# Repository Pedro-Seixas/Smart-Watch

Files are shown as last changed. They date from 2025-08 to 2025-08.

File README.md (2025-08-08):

# Smart-Watch
A custom low-power stm32-based wearable smart watch

## Features
- 6-Axis IMU Sensor for motion detection and pedometer.
- Temperature Sensor
- OLED Display
- Powered by 3.7V battery or USB
- 2 programmable switches
- Real-Time Clock
- Tap Sensor

## Pinout Diagram


## Schematic
schematic_page-0001

## PCB
<p align="center">
watch-front
watch-back
</p>

## Demo (Clock | Menu | Sensors)
<p align="center">



</p>

If you would like to clone the repo, see the "How to" in the Docs folder.

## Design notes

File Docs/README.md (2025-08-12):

# How to get it working

## Softwares needed:
- STM32CubeIDE
- STM32CubeProgrammer

## Install necessary files
- Clone the repository to a folder and in STM32CubeIDE open the project

## Upload to the device
- Build the project and open STM32CubeProgrammer.
- Select USB since we are doing DFU (See 1).
- Click "Open File" and navigate to your project folder, go to the Debug folder and select the file with the .elf extension (See 2).
- Remove the device from the USB, hold the boot button (SW2) and connect the device to the computer. Release the boot button.
- Click the refresh icon in the STM32CubeProgrammer software (See 3), it should find the device. Now, click in "Connect" (See 4). Finally, click in "Download" (See 5).
- After the download is complete, press the Reset button (SW1) or remove and connect the USB.



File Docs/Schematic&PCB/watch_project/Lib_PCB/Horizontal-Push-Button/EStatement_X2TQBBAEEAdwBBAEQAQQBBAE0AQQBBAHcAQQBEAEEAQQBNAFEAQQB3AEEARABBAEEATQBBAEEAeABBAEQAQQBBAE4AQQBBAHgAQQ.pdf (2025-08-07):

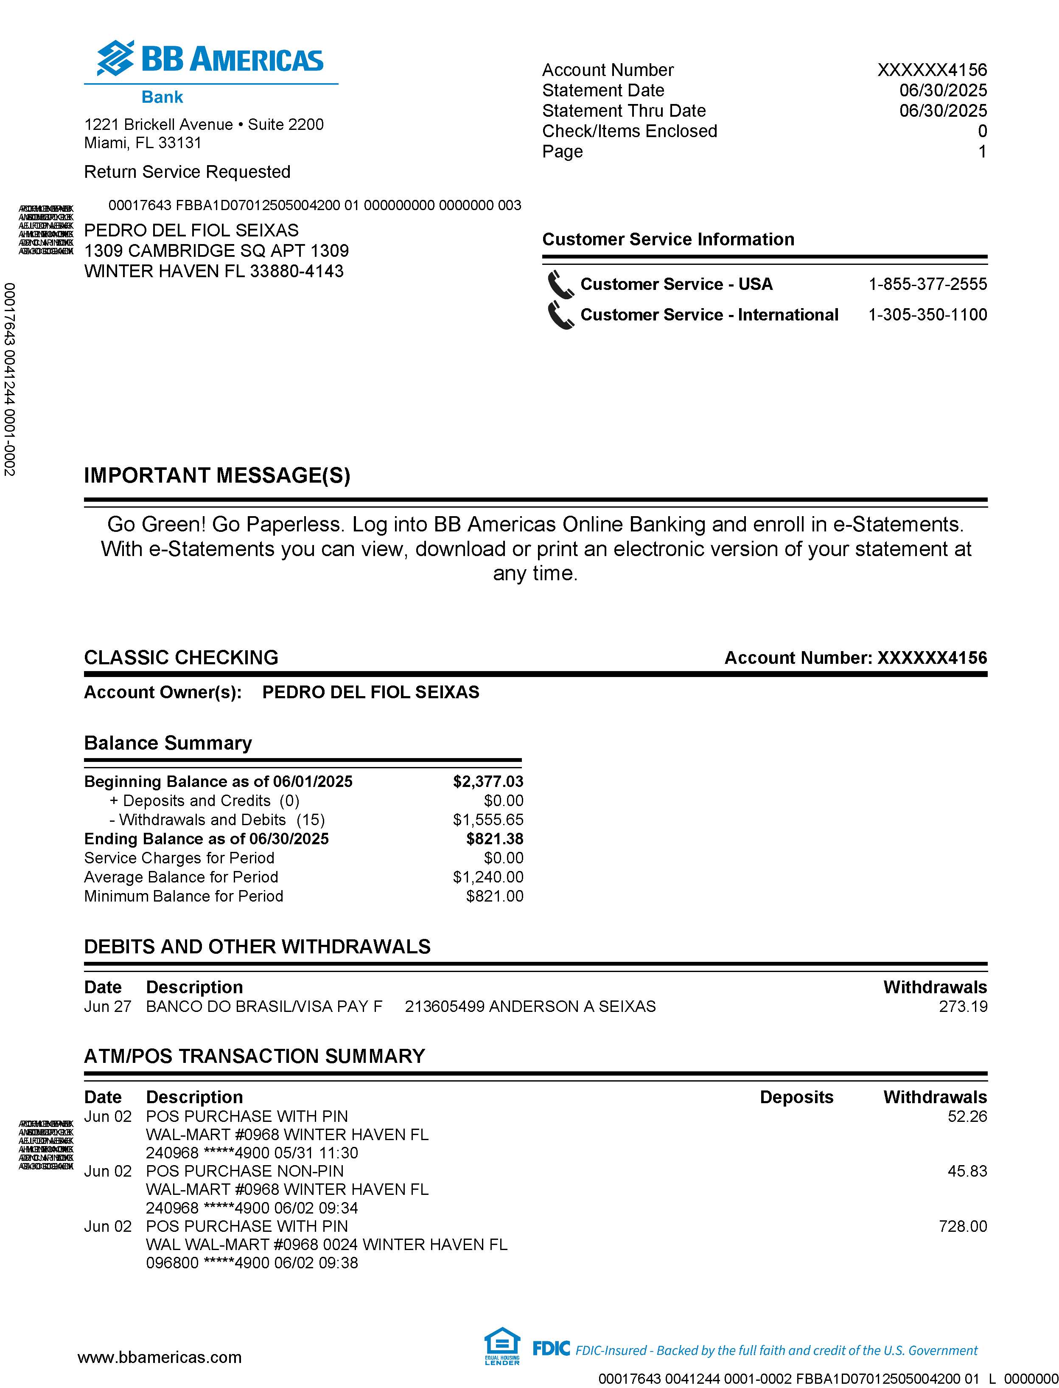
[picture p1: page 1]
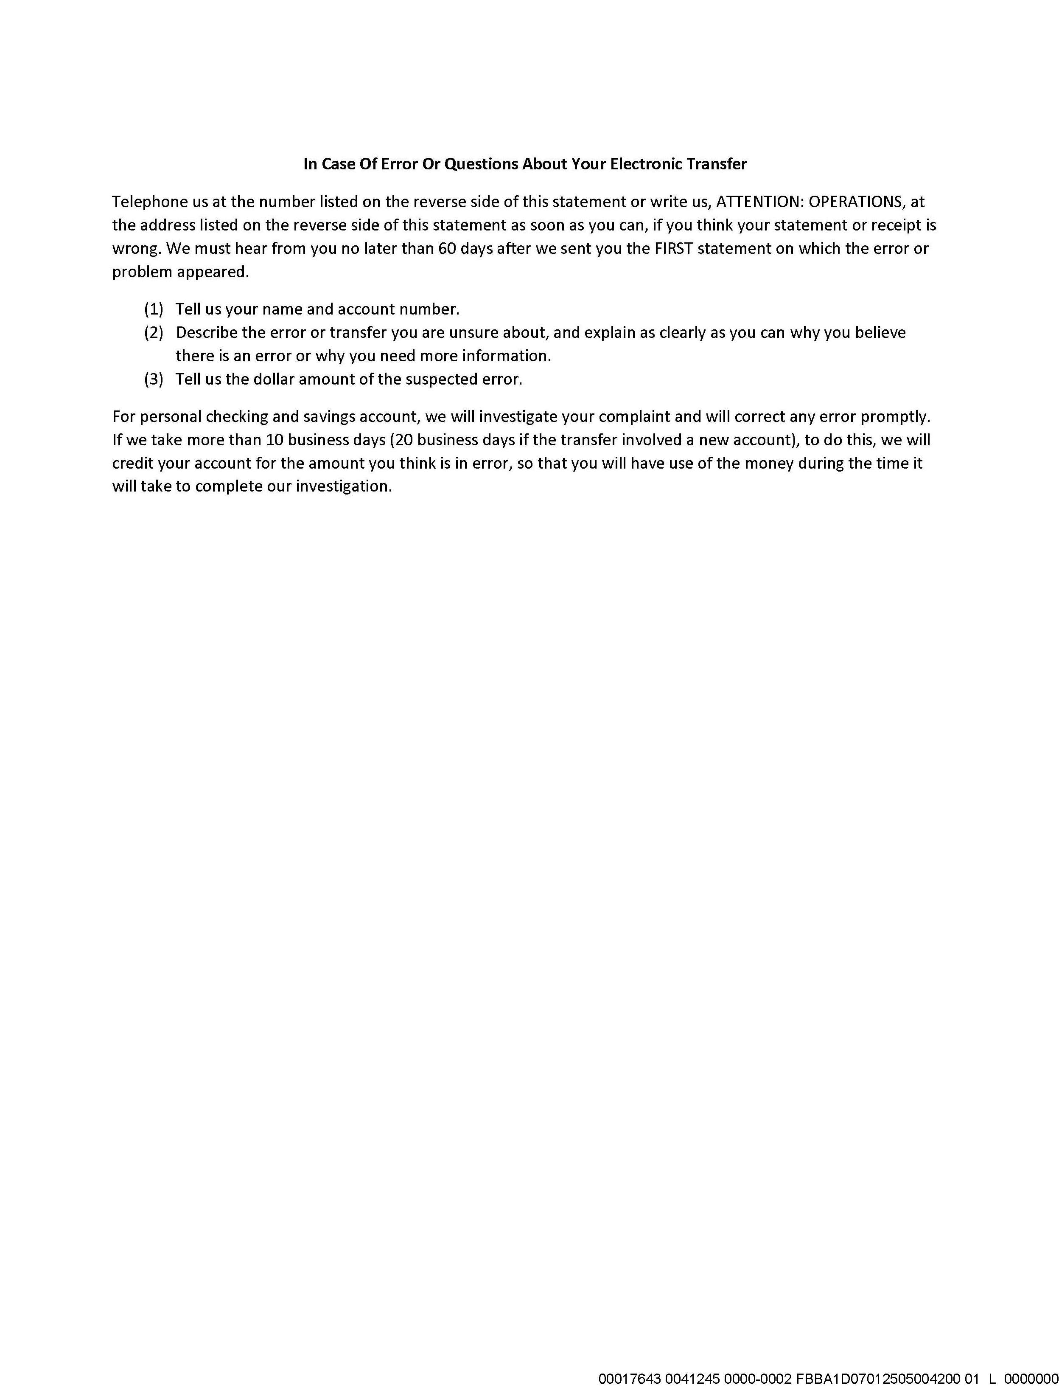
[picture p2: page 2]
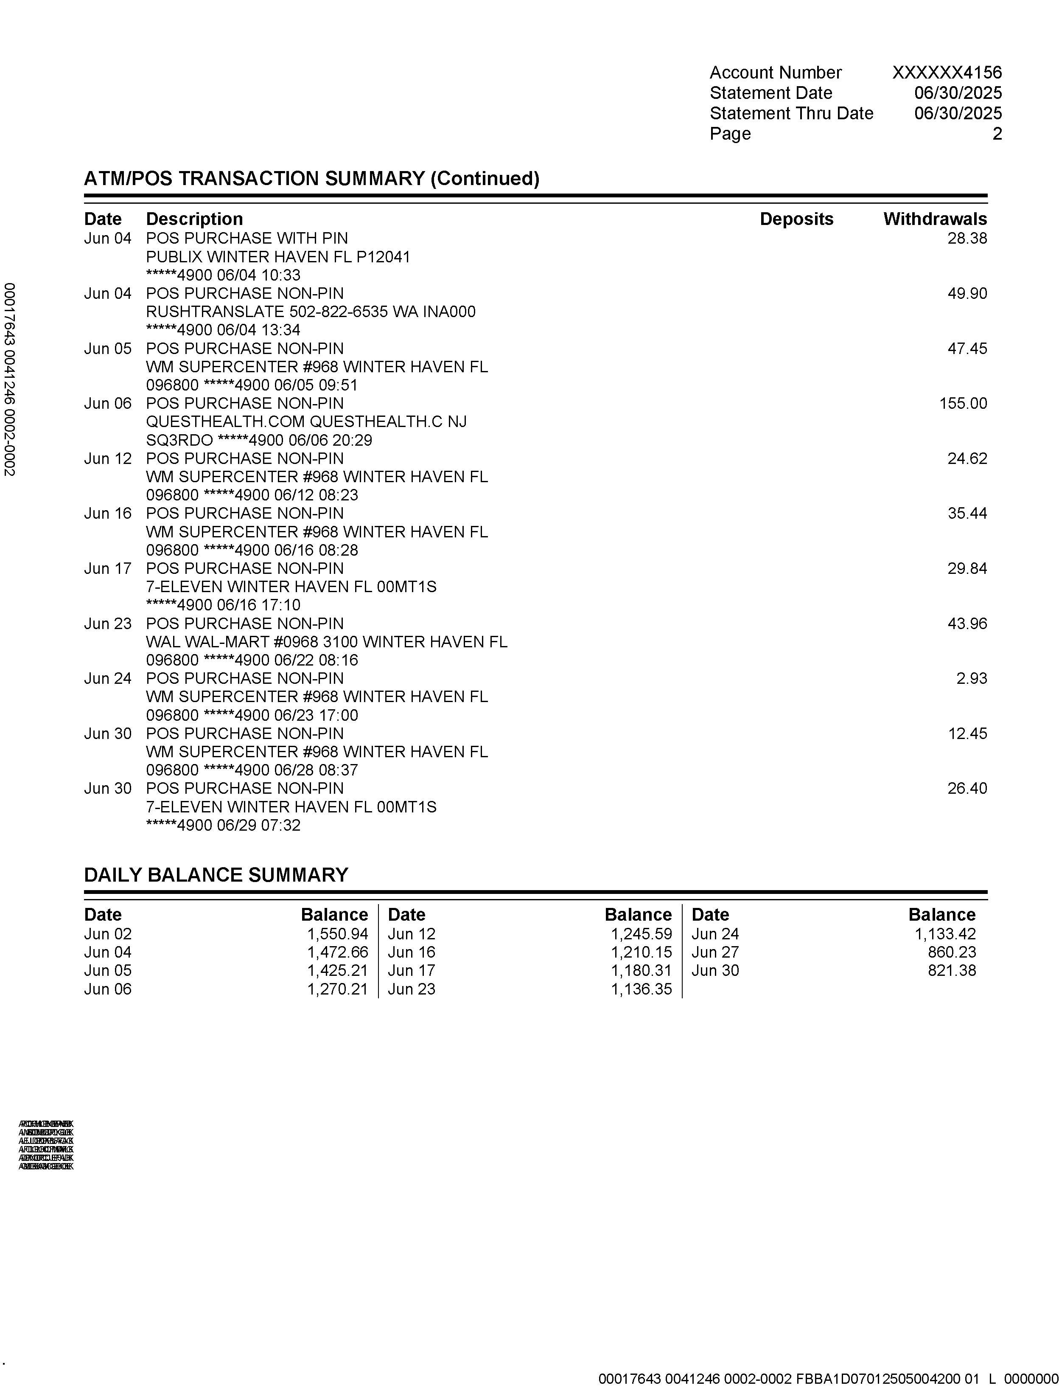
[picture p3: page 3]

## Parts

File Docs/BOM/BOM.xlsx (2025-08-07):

Comment | Designator | Footprint | Part Number
STM32 Microprocessor | U2 | Package_QFP:LQFP-48_7x7mm_P0.5mm | C465977
32.768 kHz Clock | X1 | Watch-PCB-Lib:FC-135R_L3.2-W1.5 | C32346
8 MHz Clock | X3 | Watch-PCB-Lib:CRYSTAL-SMD_4P-L3.2-W2.5-BL | C400090
0603 100nF Capacitor | C1, C2, C3, C5, C7, C8, C11, C12, C21 | Capacitor_SMD:C_0603_1608Metric | C49678
0603 10uF Capacitor | C4 | Capacitor_SMD:C_0603_1608Metric | C19702
0805 1uF Capacitor | C6, C13, C14, C17, C18, C23 | Capacitor_SMD:C_0805_2012Metric | C28323
0805 2uF Capacitor | C22 | Capacitor_SMD:C_0805_2012Metric | C5448893
0402 10pF Capacitor | C9, C10 | Capacitor_SMD:C_0402_1005Metric | C466222
0402 15pF Capacitor | C15, C16 | Capacitor_SMD:C_0402_1005Metric | C18220924
Schottky Diode | D1, D2 | Watch-PCB-Lib:SOD-123_L2.7-W1.6-LS3.7-RD | C82544
LED | D3 | Watch-PCB-Lib:LED0805-R-RD | C84256
2-P Header | J1 | Watch-PCB-Lib:HDR-TH_2P-P2.00-H-M_2005WR-2P | C6837611
MicroUSB Connector | J3 | Watch-PCB-Lib:MICRO-USB-SMD_5P-P0.65-H-F_C10418 | C10418
OLED Display | OLED1 | Watch-PCB-Lib:OLED_0.96-30P-P0.70-12864 | C2890596
0805 10kohms Resistor | R1, R2, R3, R5, R6, R7 | Resistor_SMD:R_0805_2012Metric | C17414
0603 1.5kohms Resistor | R4 | Resistor_SMD:R_0603_1608Metric | C22843
0805 270ohms Resistor | R8 | Resistor_SMD:R_0805_2012Metric | C17590
0805 390kohms Resistor | R9 | Resistor_SMD:R_0805_2012Metric | C17656
SMD Push Button | SW1, SW2 | Watch-PCB-Lib:SW-SMD_L3.9-W3.0-P4.45 | C720477
Horizontal Push Button | SW3, SW4 | Watch-PCB-Lib:KEY-TH_K2-1109DE-CXXW-XX | C455252
Accelerometer and Gyroscope | U1 | Watch-PCB-Lib:LGA-14_L3.0-W2.5-P0.50-TL | C967633
LDO 3.3V | U3 | Package_TO_SOT_SMD:SOT-23-5 | C51118

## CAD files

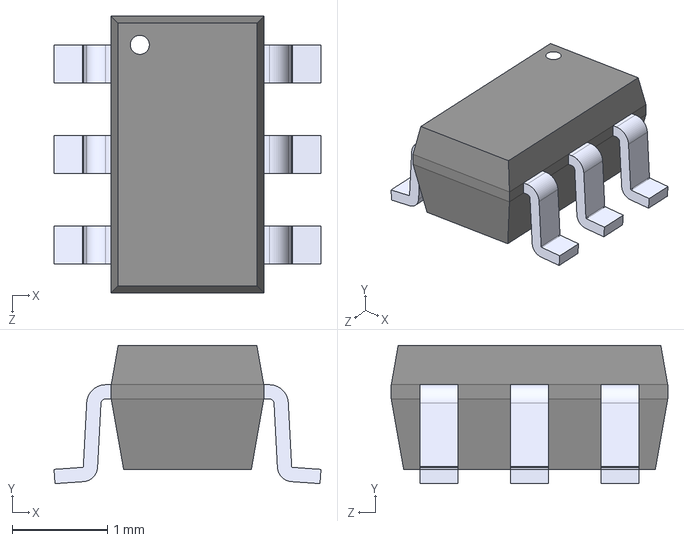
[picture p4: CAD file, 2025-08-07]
Docs/Schematic&PCB/watch_project/Lib_PCB/DW01A/DW01A.step
2.80 x 1.45 x 2.90 mm

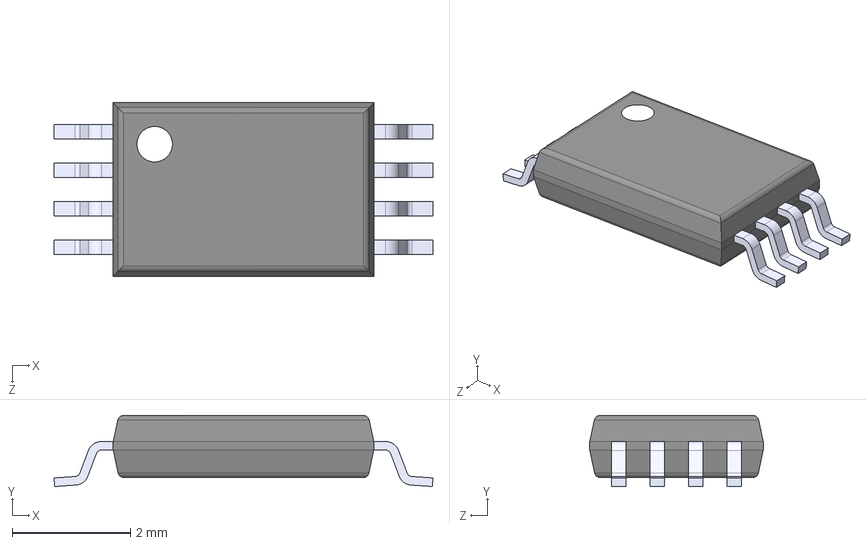
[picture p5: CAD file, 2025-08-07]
Docs/Schematic&PCB/watch_project/Lib_PCB/MOSFETSS/FS8205A.step
6.40 x 1.20 x 2.93 mm

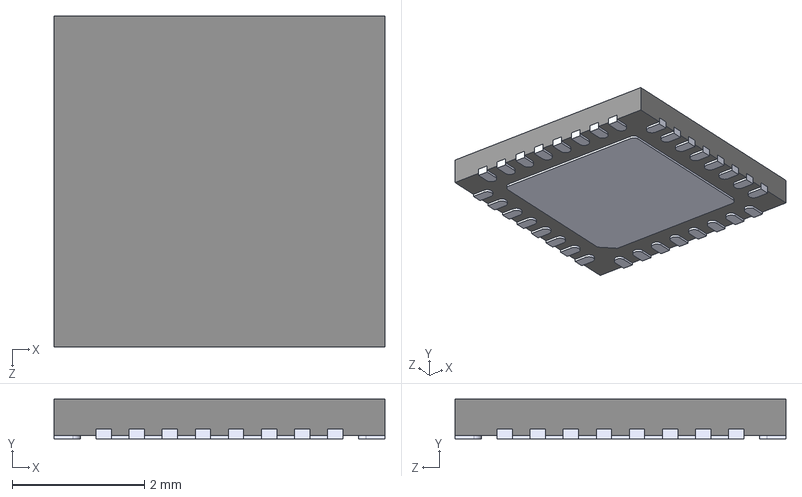
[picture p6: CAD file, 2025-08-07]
Docs/Schematic&PCB/watch_project/Lib_PCB/STM/QFN50P500X500X60-33N.step
5.00 x 0.6 x 5.00 mm

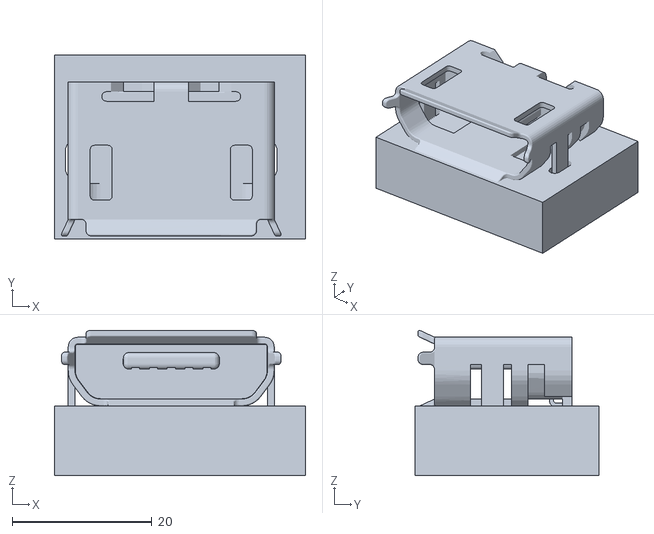
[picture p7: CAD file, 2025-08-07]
Docs/Schematic&PCB/watch_project/Lib_PCB/USB-Connector/OBJ_MICRO-USB-SMD_5P-P0.65-H-F_C10418.obj
36.0 x 26.3 x 20.8

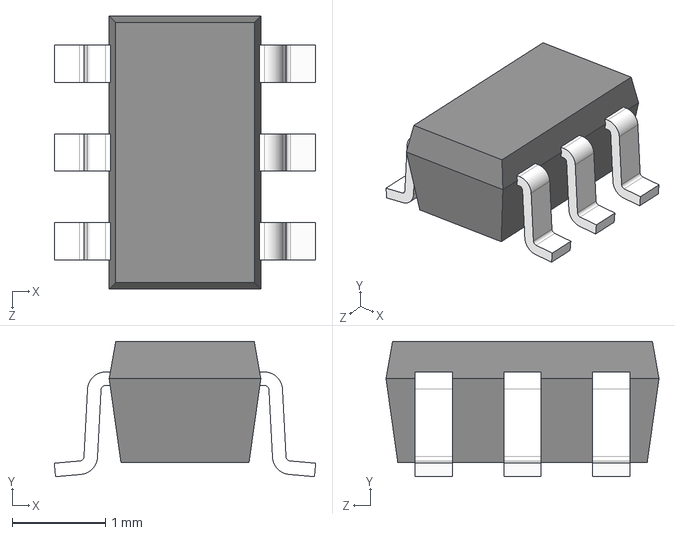
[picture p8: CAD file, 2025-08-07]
Docs/Schematic&PCB/watch_project/Lib_PCB/USBLC6-2SC6/USBLC6-2SC6.step
2.80 x 1.45 x 2.92 mm

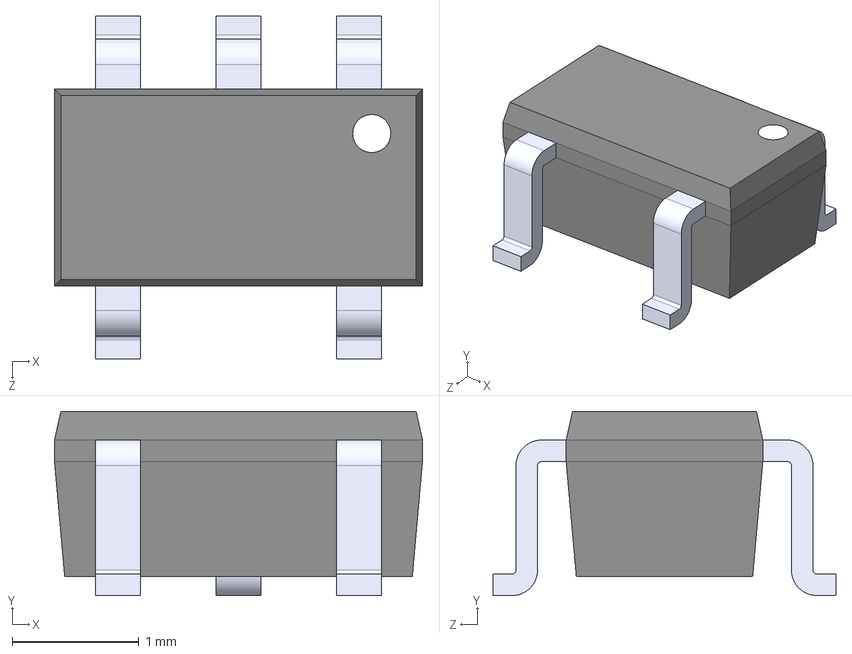
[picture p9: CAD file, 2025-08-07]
Docs/Schematic&PCB/watch_project/Lib_PCB/ICCharger/MCP73831T-4ADI_OT.step
2.90 x 1.45 x 2.70 mm

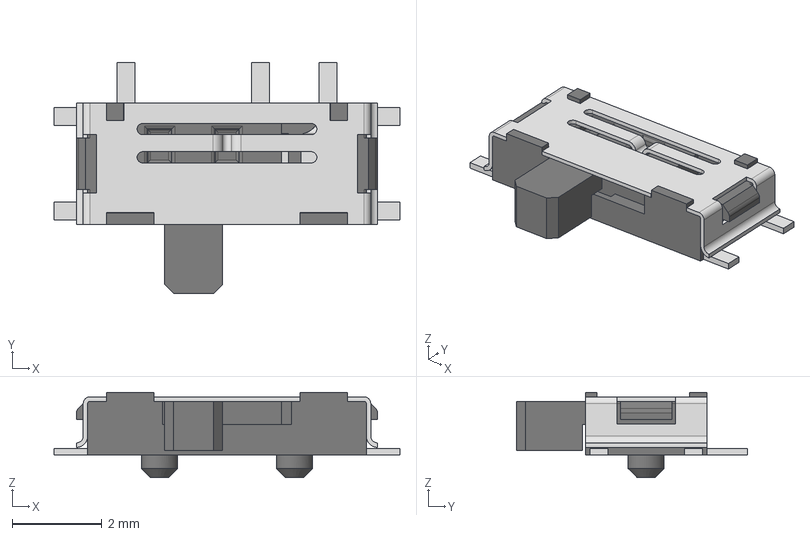
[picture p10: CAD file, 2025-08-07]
Docs/Schematic&PCB/watch_project/Lib_PCB/SlideSwitch/450404015514.step
7.70 x 5.13 x 1.90 mm
Frame
Pin 4
Frame 1
Pin 1
Pin 2
Pin 3
Slider 1
Slider
Cover

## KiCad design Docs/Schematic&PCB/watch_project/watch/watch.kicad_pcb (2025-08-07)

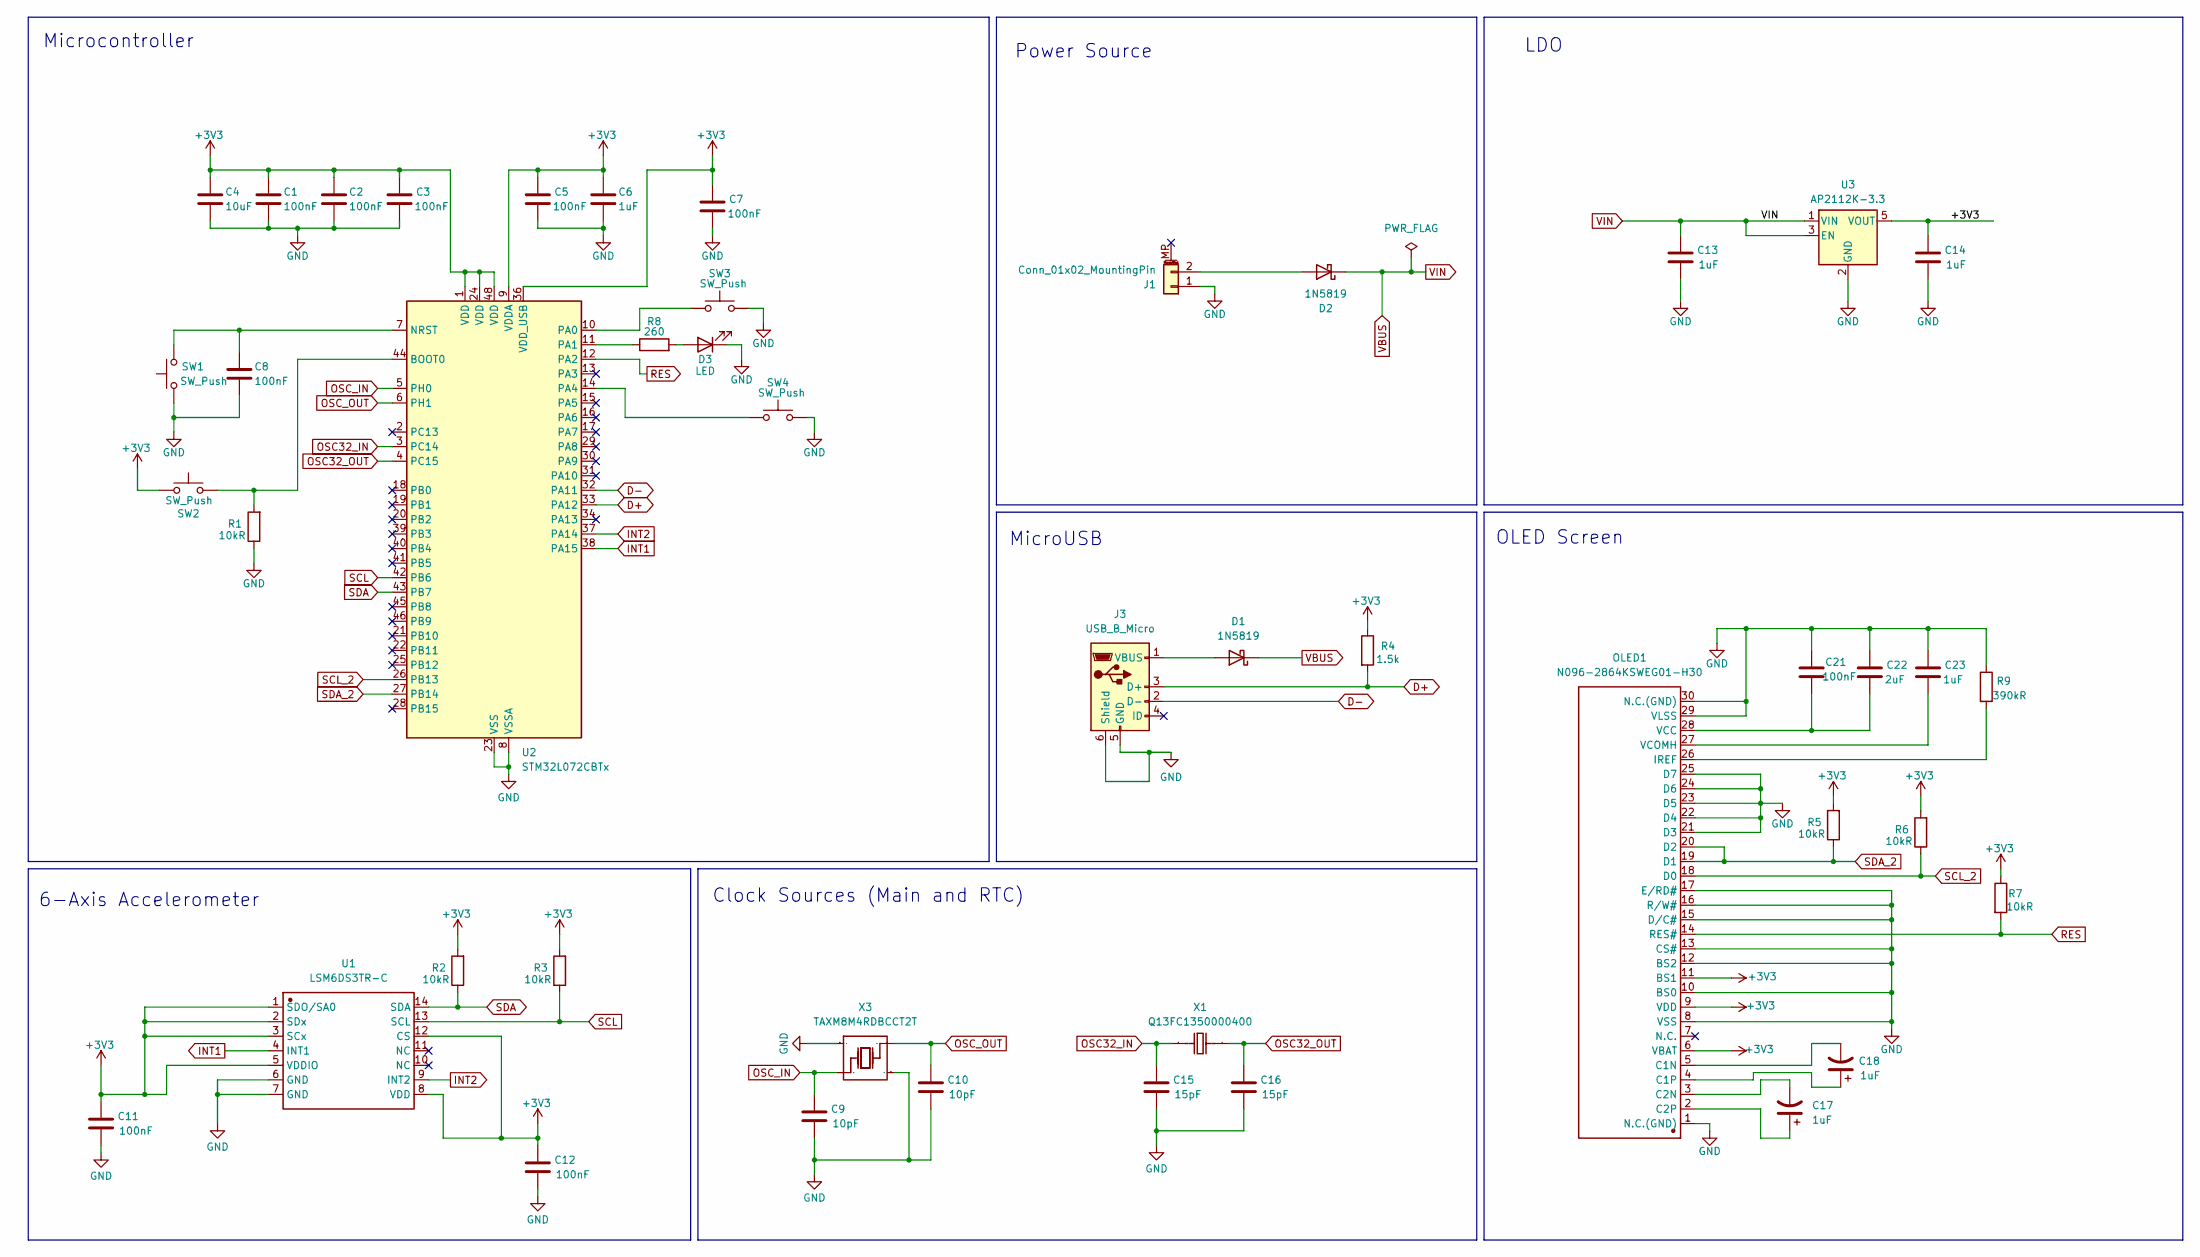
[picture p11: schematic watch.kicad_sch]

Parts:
C1, C2, C3, C5, C7, C8, C11, C12, C21: 100nF; C_0603_1608Metric
C4: 10uF; C_0603_1608Metric
C6, C13, C14, C17, C18, C23: 1uF; C_0805_2012Metric
C9, C10: 10pF; C_0402_1005Metric
C15, C16: 15pF; C_0402_1005Metric
C22: 2uF; C_0805_2012Metric
D1, D2: 1N5819; SOD-123_L2.7-W1.6-LS3.7-RD; JLC_3DModel 4d7f235d12124480ae44c354a7fd93dd
D3: LED; LED0805-R-RD
J1: Conn_01x02_MountingPin; HDR-TH_2P-P2.00-H-M_2005WR-2P; JLC_3DModel bbbe6f8a9a8948aa8046efa4a5376ae2
J3: USB_B_Micro; MICRO-USB-SMD_5P-P0.65-H-F_C10418; JLC_3DModel 8d98bdb22dfe41cea8df3303517703a8
OLED1: N096-2864KSWEG01-H30; OLED_0.96-30P-P0.70-12864; Manufacturer Part N096-2864KSWEG01-H30; JLC_3DModel 051045abecb44869adf3d7bdc1667540
R1, R2, R3, R5, R6, R7: 10kR; R_0805_2012Metric
R4: 1.5k; R_0603_1608Metric
R8: 260; R_0805_2012Metric
R9: 390kR; R_0805_2012Metric
SW1, SW2: SW_Push; SW-SMD_L3.9-W3.0-P4.45; JLC_3DModel 2e35dca8e7854ed683469f8d54d1ef17
SW3, SW4: SW_Push; SW-Horz
U1: LSM6DS3TR-C; LGA-14_L3.0-W2.5-P0.50-TL; Manufacturer Part LSM6DS3TR-C
U2: STM32L072CBTx; LQFP-48_7x7mm_P0.5mm
U3: AP2112K-3.3; SOT-23-5
X1: Q13FC1350000400; FC-135R_L3.2-W1.5; Manufacturer Part Q13FC13500004
X3: TAXM8M4RDBCCT2T; CRYSTAL-SMD_4P-L3.2-W2.5-BL; Manufacturer Part TAXM8M4RDBCCT2T

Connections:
+3V3: C1.1, C2.1, C3.1, C4.1, C5.1, C6.1, C7.1, C11.1, C12.1, C14.1, OLED1.6 (VBAT), OLED1.9 (VDD), OLED1.11 (BS1), R2.2, R3.2, R4.1, R5.2, R6.2, R7.1, SW2.1, U1.1 (SDO/SA0), U1.2 (SDx), U1.3 (SCx), U1.5 (VDDIO), U1.8 (VDD), U1.12 (CS), U2.1 (VDD), U2.9 (VDDA), U2.24 (VDD), U2.36 (VDD_USB), U2.48 (VDD), U3.5 (VOUT)
D+: J3.3 (D+), R4.2, U2.33 (PA12)
D-: J3.2 (D-), U2.32 (PA11)
GND: C1.2, C2.2, C3.2, C4.2, C5.2, C6.2, C7.2, C8.2, C9.2, C10.2, C11.2, C12.2, C13.2, C14.2, C15.2, C16.2, C21.1, C22.1, C23.1, D3.1 (K), J1.1, J3.5 (GND), J3.6 (Shield), OLED1.1 (N.C.(GND)), OLED1.8 (VSS), OLED1.10 (BS0), OLED1.12 (BS2), OLED1.13 (CS#), OLED1.15 (D/C#), OLED1.16 (R/W#), OLED1.17 (E/RD#), OLED1.21 (D3), OLED1.22 (D4), OLED1.23 (D5), OLED1.24 (D6), OLED1.25 (D7), OLED1.29 (VLSS), OLED1.30 (N.C.(GND)), R1.1, R9.1, SW1.1, SW3.2, SW4.2, U1.6 (GND), U1.7 (GND), U2.8 (VSSA), U2.23 (VSS), U2.35 (VSS), U2.47 (VSS), U3.2 (GND), X3.2, X3.4
INT1: U1.4 (INT1), U2.38 (PA15)
INT2: U1.9 (INT2), U2.37 (PA14)
unnamed: D1.2 (A), J3.1 (VBUS)
unnamed: D2.2 (A), J1.2
unnamed: D3.2 (A), R8.2
unnamed: C18.2, OLED1.5 (C1N)
unnamed: C18.1, OLED1.4 (C1P)
unnamed: C17.2, OLED1.3 (C2N)
unnamed: C17.1, OLED1.2 (C2P)
unnamed: OLED1.26 (IREF), R9.2
unnamed: C21.2, C22.2, OLED1.28 (VCC)
unnamed: C23.2, OLED1.27 (VCOMH)
unnamed: R1.2, SW2.2, U2.44 (BOOT0)
unnamed: C8.1, SW1.2, U2.7 (NRST)
unnamed: SW3.1, U2.10 (PA0)
unnamed: R8.1, U2.11 (PA1)
unnamed: SW4.1, U2.14 (PA4)
OSC32_IN: C15.1, U2.3 (PC14), X1.1
OSC32_OUT: C16.1, U2.4 (PC15), X1.2
OSC_IN: C9.1, U2.5 (PH0), X3.1
OSC_OUT: C10.1, U2.6 (PH1), X3.3
RES: OLED1.14 (RES#), R7.2, U2.12 (PA2)
SCL: R3.1, U1.13 (SCL), U2.42 (PB6)
SCL_2: OLED1.18 (D0), R6.1, U2.26 (PB13)
SDA: R2.1, U1.14 (SDA), U2.43 (PB7)
SDA_2: OLED1.19 (D1), OLED1.20 (D2), R5.1, U2.27 (PB14)
VBUS: C13.1, D1.1 (K), D2.1 (K), U3.1 (VIN), U3.3 (EN)

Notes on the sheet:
LDO
MicroUSB
Power Source
Clock Sources (Main and RTC)
6-Axis Accelerometer
OLED Screen
Microcontroller

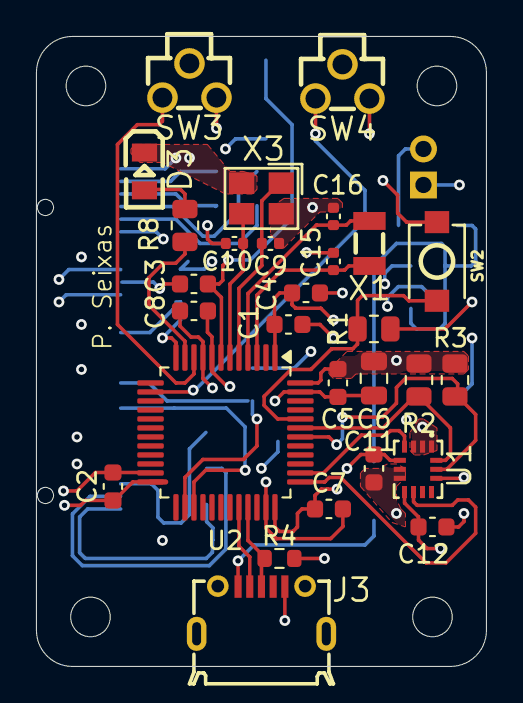
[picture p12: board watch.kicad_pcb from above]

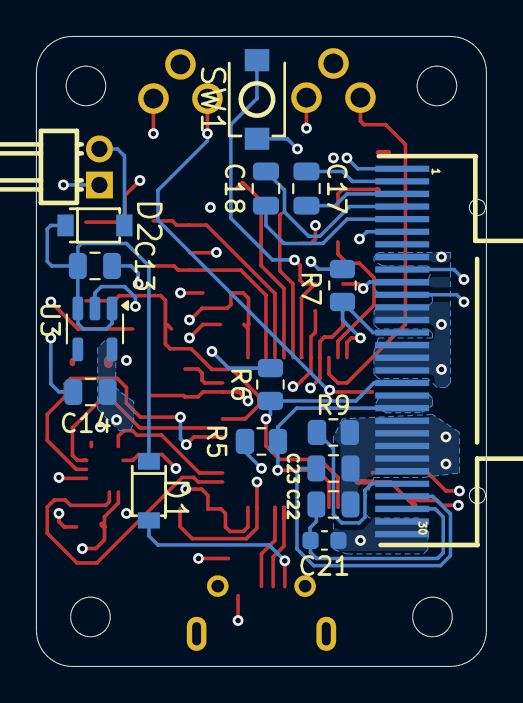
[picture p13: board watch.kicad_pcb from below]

Board: 4 copper layers, 25.0 x 35.0 mm, 45 parts (17 on the bottom side), 31 nets.

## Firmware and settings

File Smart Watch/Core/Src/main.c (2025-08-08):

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
/* Includes ------------------------------------------------------------------*/
#include "main.h"
#include "cmsis_os.h"
#include "usb_device.h"

/* USER CODE BEGIN Includes */
#include "ssd1306.h"
#include "ssd1306_fonts.h"
#include "lsm6ds3tr-c.h"

/* USER CODE END Includes */

/* USER CODE BEGIN PTD */
 RTC_TimeTypeDef sTime;
 RTC_DateTypeDef sDate;
/* USER CODE END PTD */

/* USER CODE BEGIN PD */

 typedef enum{
	  DISPLAY_CLOCK,
	  DISPLAY_CONFIG,
	  DISPLAY_SENSORS,
	  DISPLAY_OPTIONS,
	  DISPLAY_ACTIVE,
	  DISPLAY_INACTIVE
 } menu;

 // Flags for the menu
 volatile menu main_menu;
 volatile uint8_t select_pressed = 0;
 volatile uint32_t button_last_pressed;
/* USER CODE END PD */

I2C_HandleTypeDef hi2c1;
I2C_HandleTypeDef hi2c2;

RTC_HandleTypeDef hrtc;

/* Definitions for menu */
osThreadId_t menuHandle;
const osThreadAttr_t menu_attributes = {
  .name = "menu",
  .stack_size = 512 * 4,
  .priority = (osPriority_t) osPriorityNormal,
};
/* Definitions for imu */
osThreadId_t imuHandle;
const osThreadAttr_t imu_attributes = {
  .name = "imu",
  .stack_size = 128 * 4,
  .priority = (osPriority_t) osPriorityLow,
};
void SystemClock_Config(void);
static void MX_GPIO_Init(void);
static void MX_I2C1_Init(void);
static void MX_I2C2_Init(void);
static void MX_RTC_Init(void);
void Menu_Task(void *argument);
void Imu_Task(void *argument);

/* USER CODE BEGIN 0 */

void menu_display_time(){
	HAL_RTC_GetTime(&hrtc, &sTime, RTC_FORMAT_BIN);
	HAL_RTC_GetDate(&hrtc, &sDate, RTC_FORMAT_BIN);

	char hour[100];
	char minute[100];

	ssd1306_Fill(Black);

	snprintf(hour, sizeof(hour), "%02d", sTime.Hours);
	snprintf(minute, sizeof(minute), "%02d", sTime.Minutes);

	// Show time (hour above minutes)
	ssd1306_SetCursor(16, 32);
	ssd1306_WriteString(hour, Font_16x26, White);
	ssd1306_SetCursor(16, 60);
	ssd1306_WriteString(minute, Font_16x26, White);
	ssd1306_UpdateScreen();

	// Go to menu
	if(!HAL_GPIO_ReadPin(GPIOA, GPIO_PIN_4)){
		vTaskDelay(pdMS_TO_TICKS(300));
		main_menu = DISPLAY_OPTIONS;
		button_last_pressed = HAL_GetTick();
	}
}

void show_menu(){
	menu static current_selected = DISPLAY_CLOCK;

	ssd1306_Fill(Black);

	// Navigate menu options
	if(select_pressed){
		current_selected = (current_selected + 1) % 3;
		select_pressed = 0;
	}

	// Select menu option
	if(!HAL_GPIO_ReadPin(GPIOA, GPIO_PIN_4)){
		main_menu = current_selected;
		button_last_pressed = HAL_GetTick();
	}

	// Show which option is selected
	switch(current_selected){
		case DISPLAY_CLOCK:
			ssd1306_SetCursor(2, 0);
			ssd1306_WriteString(">Clock", Font_7x10, White);
			ssd1306_SetCursor(2, 24);
			ssd1306_WriteString("Config", Font_7x10, White);
			ssd1306_SetCursor(2, 48);
			ssd1306_WriteString("Sensors", Font_7x10, White);
			break;
		case DISPLAY_CONFIG:
			ssd1306_SetCursor(2, 0);
			ssd1306_WriteString("Clock", Font_7x10, White);
			ssd1306_SetCursor(2, 24);
			ssd1306_WriteString(">Config", Font_7x10, White);
			ssd1306_SetCursor(2, 48);
			ssd1306_WriteString("Sensors", Font_7x10, White);
			break;
		case DISPLAY_SENSORS:
			ssd1306_SetCursor(2, 0);
			ssd1306_WriteString("Clock", Font_7x10, White);
			ssd1306_SetCursor(2, 24);
			ssd1306_WriteString("Config", Font_7x10, White);
			ssd1306_SetCursor(2, 48);
			ssd1306_WriteString(">Sensors", Font_7x10, White);
			break;
		default:
			break;
	}

	ssd1306_UpdateScreen();
}

void show_sensors(){
	int16_t ax, ay, az, gx, gy, gz;
	char gyro[50];
	char accel[50];
	char steps[50];
	uint16_t step;
	//char temp[50];

	// Go to menu
	if(!HAL_GPIO_ReadPin(GPIOA, GPIO_PIN_4)){
		vTaskDelay(pdMS_TO_TICKS(300));
		main_menu = DISPLAY_OPTIONS;
		button_last_pressed = HAL_GetTick();
	}

	// Read Sensors
	lsm6ds3tr_c_read_gyro(&gx, &gy, &gz);
	lsm6ds3tr_c_read_accel(&ax, &ay, &az);
	lsm6ds3tr_c_read_step_count(&step);
	//LSM6DS3_ReadTemp(&hi2c1, &tempInt);

	// Display Sensors
	ssd1306_Fill(Black);

	// Convert to string
	snprintf(gyro, sizeof(gyro), "%d,%d,%d", map_to_range(gx), map_to_range(gy), map_to_range(gz));
	snprintf(accel, sizeof(accel), "%d,%d,%d", map_to_range(ax), map_to_range(ay), map_to_range(az));
	snprintf(steps, sizeof(steps), "%d", step);
	//snprintf(temp, sizeof(temp), "%d", convert_to_fahrenheit(tempInt));

	ssd1306_SetCursor(16, 0);
	ssd1306_WriteString("Gyro", Font_6x8, White);
	ssd1306_SetCursor(2, 12);
	ssd1306_WriteString(gyro, Font_6x8, White);

	ssd1306_SetCursor(16, 24);
	ssd1306_WriteString("Accel", Font_6x8, White);
	ssd1306_SetCursor(2, 36);
	ssd1306_WriteString(accel, Font_6x8, White);

	ssd1306_SetCursor(16, 48);
	ssd1306_WriteString("Steps", Font_6x8, White);
	ssd1306_SetCursor(2, 60);
	ssd1306_WriteString(steps, Font_6x8, White);

	// Removed Temperature as it is not reliable
	/*
	ssd1306_SetCursor(16, 48);
	ssd1306_WriteString("Temp", Font_6x8, White);
	ssd1306_SetCursor(16, 58);
	ssd1306_WriteString(temp, Font_6x8, White);
	 */
	ssd1306_UpdateScreen();
	vTaskDelay(pdMS_TO_TICKS(100));
}

void menu_change_time(){
    typedef enum{
        STATE_EDIT_HOUR,
        STATE_EDIT_MINUTE,
        STATE_CONFIRM_FIELD
    } MenuState;

    HAL_RTC_GetTime(&hrtc, &sTime, RTC_FORMAT_BIN);
    HAL_RTC_GetDate(&hrtc, &sDate, RTC_FORMAT_BIN);

    char hour[50];
    char minute[50];

    ssd1306_Fill(Black);

    static MenuState menu_selected = STATE_EDIT_HOUR;

    snprintf(hour, sizeof(hour), "%02d", sTime.Hours);
    snprintf(minute, sizeof(minute), "%02d", sTime.Minutes);

    // Select hour or minute
    if(select_pressed){
        menu_selected = (menu_selected + 1) % 3;
        select_pressed = 0;
    }

    // Auto-repeat button variables
    static int button_was_pressed = 0;
    static uint32_t press_start_tick = 0;
    static uint32_t last_repeat_tick = 0;

    int button_pressed = !HAL_GPIO_ReadPin(GPIOA, GPIO_PIN_4);

    uint32_t current_tick = osKernelGetTickCount();

    // Auto-repeat timing constants
    const uint32_t initial_delay = 500 / portTICK_PERIOD_MS;
    const uint32_t repeat_interval = 100 / portTICK_PERIOD_MS;

    if(button_pressed){
    	button_last_pressed = HAL_GetTick();
        if(!button_was_pressed){
            // Button just pressed, increment once
            if(menu_selected == STATE_EDIT_HOUR){
                if(sTime.Hours < 23) sTime.Hours++;
                else sTime.Hours = 0;
                HAL_RTC_SetTime(&hrtc, &sTime, RTC_FORMAT_BIN);
            }
            else if(menu_selected == STATE_EDIT_MINUTE){
                if(sTime.Minutes < 59) sTime.Minutes++;
                else sTime.Minutes = 0;
                HAL_RTC_SetTime(&hrtc, &sTime, RTC_FORMAT_BIN);
            }
            else if(menu_selected == STATE_CONFIRM_FIELD){
                main_menu = DISPLAY_OPTIONS;
            }
            press_start_tick = current_tick;
            last_repeat_tick = current_tick;
        } else {
            // Button held down, increment fast
            if((current_tick - press_start_tick) > initial_delay &&
               (current_tick - last_repeat_tick) > repeat_interval){
                // Repeat increment
                if(menu_selected == STATE_EDIT_HOUR){
                    if(sTime.Hours < 23) sTime.Hours++;
                    else sTime.Hours = 0;
                    HAL_RTC_SetTime(&hrtc, &sTime, RTC_FORMAT_BIN);
                }
                else if(menu_selected == STATE_EDIT_MINUTE){
                    if(sTime.Minutes < 59) sTime.Minutes++;
                    else sTime.Minutes = 0;
                    HAL_RTC_SetTime(&hrtc, &sTime, RTC_FORMAT_BIN);
                }

                last_repeat_tick = current_tick;
            }
        }
    } else {
        // Reset
        button_was_pressed = 0;
        press_start_tick = 0;
        last_repeat_tick = 0;
    }

    button_was_pressed = button_pressed;

    // Show cursors ( > ) based on the current state
    switch(menu_selected){
        case STATE_EDIT_HOUR:
            ssd1306_SetCursor(2, 32);
            ssd1306_WriteString(">", Font_11x18, White);
            break;
        case STATE_EDIT_MINUTE:
            ssd1306_SetCursor(2, 60);
            ssd1306_WriteString(">", Font_11x18, White);
            break;
        case STATE_CONFIRM_FIELD:
            ssd1306_SetCursor(2, 105);
            ssd1306_WriteString(">", Font_11x18, White);
            break;
    }

    // Show time (hour above minutes)
    ssd1306_SetCursor(16, 32);
    ssd1306_WriteString(hour, Font_16x26, White);
    ssd1306_SetCursor(16, 60);
    ssd1306_WriteString(minute, Font_16x26, White);
    ssd1306_SetCursor(16, 105);
    ssd1306_WriteString("Save", Font_11x18, White);
    ssd1306_UpdateScreen();
}

void menu_inactive(){
	ssd1306_SetDisplayOn(0);

	// If any event occurs, turn on the display
	if(lsm6ds3tr_c_read_wrist(&hi2c1) || select_pressed || (!HAL_GPIO_ReadPin(GPIOA, GPIO_PIN_4))){
		main_menu = DISPLAY_ACTIVE;
	}
}

void menu_active(){
	  ssd1306_SetDisplayOn(1);
	  button_last_pressed = HAL_GetTick();
	  select_pressed = 0;
	  main_menu = DISPLAY_CLOCK;
}

void HAL_GPIO_EXTI_Callback(uint16_t GPIO_Pin){
	switch(GPIO_Pin){
		case GPIO_PIN_0:
			select_pressed = 1;
			button_last_pressed = HAL_GetTick();
			break;
		case GPIO_PIN_15:
			if(ssd1306_GetDisplayOn()){
				main_menu = DISPLAY_INACTIVE;
			}else{
				main_menu = DISPLAY_ACTIVE;
			}
			break;
		default:
			break;
	}
}
/* USER CODE END 0 */

/**
  * @brief  The application entry point.
  * @retval int
  */
int main(void)
{

  /* MCU Configuration--------------------------------------------------------*/

  /* Reset of all peripherals, Initializes the Flash interface and the Systick. */
  HAL_Init();

  /* Configure the system clock */
  SystemClock_Config();

  /* USER CODE BEGIN SysInit */
  /* init code for USB_DEVICE */
  MX_USB_DEVICE_Init();
  /* USER CODE END SysInit */

  /* Initialize all configured peripherals */
  MX_GPIO_Init();
  MX_I2C1_Init();
  MX_I2C2_Init();
  MX_RTC_Init();
  /* USER CODE BEGIN 2 */

  // This is necessary for OLED Screen power-up
  HAL_GPIO_WritePin(GPIOA, GPIO_PIN_2, 0);
  HAL_Delay(1);
  HAL_GPIO_WritePin(GPIOA, GPIO_PIN_2, 1);
  HAL_Delay(100);

  // Init accelerometer and gyroscope
  lsm6ds3tr_c_init();

  // Init Pedometer
  lsm6ds3tr_c_pedometer_init();

  // Init Wrist Tilt
  lsm6ds3tr_c_wrist_tilt_init();

  // Tap Init
  lsm6ds3tr_c_tap_cfg();

  // OLED Screen
  ssd1306_Init();
  ssd1306_Fill(Black);
  ssd1306_SetCursor(2, 0);
  ssd1306_WriteString("Hello", Font_11x18, White);
  ssd1306_SetCursor(2, 32);
  ssd1306_WriteString("World", Font_11x18, White);
  ssd1306_UpdateScreen();

  /* USER CODE END 2 */

  /* Init scheduler */
  osKernelInitialize();

  /* USER CODE BEGIN RTOS_MUTEX */
  /* add mutexes, ... */
  /* USER CODE END RTOS_MUTEX */

  /* USER CODE BEGIN RTOS_SEMAPHORES */
  /* add semaphores, ... */
  /* USER CODE END RTOS_SEMAPHORES */

  /* USER CODE BEGIN RTOS_TIMERS */
  /* start timers, add new ones, ... */
  /* USER CODE END RTOS_TIMERS */

  /* USER CODE BEGIN RTOS_QUEUES */
  /* add queues, ... */
  /* USER CODE END RTOS_QUEUES */

  /* Create the thread(s) */
  /* creation of menu */
  menuHandle = osThreadNew(Menu_Task, NULL, &menu_attributes);

  /* creation of imu */
  imuHandle = osThreadNew(Imu_Task, NULL, &imu_attributes);

  /* USER CODE BEGIN RTOS_THREADS */
  /* add threads, ... */
  /* USER CODE END RTOS_THREADS */

  /* USER CODE BEGIN RTOS_EVENTS */
  /* add events, ... */
  /* USER CODE END RTOS_EVENTS */

  /* Start scheduler */
  osKernelStart();

  /* We should never get here as control is now taken by the scheduler */

  /* Infinite loop */
  /* USER CODE BEGIN WHILE */
  while (1)
  {
    /* USER CODE END WHILE */

    /* USER CODE BEGIN 3 */
  }
  /* USER CODE END 3 */
}

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
/* USER CODE BEGIN Header_Menu_Task */
/**
  * @brief  Function implementing the menu thread.
  * @param  argument: Not used
  * @retval None
  */
/* USER CODE END Header_Menu_Task */
void Menu_Task(void *argument)
{
  /* init code for USB_DEVICE */
  MX_USB_DEVICE_Init();
  /* USER CODE BEGIN 5 */
  main_menu = DISPLAY_CLOCK;

  // Timer for turn off the screen if watch is not being used
  button_last_pressed = HAL_GetTick();
  uint32_t delayMs = 15000;
  /* Infinite loop */
  for(;;)
  {
	  // Screen Display Timer
	  if ((HAL_GetTick() - button_last_pressed) >= delayMs) {
	      main_menu = DISPLAY_INACTIVE;
	      button_last_pressed = HAL_GetTick();
	      select_pressed = 0;
	  }

	  switch(main_menu){
	  	  case DISPLAY_CLOCK:
	  		  menu_display_time();
	  		  break;
	  	  case DISPLAY_CONFIG:
	  	  	  menu_change_time();
	  		  break;
	  	  case DISPLAY_SENSORS:
	  		  show_sensors();
	  		  break;
	  	  case DISPLAY_OPTIONS:
	  		  show_menu();
	  		  break;
	  	  case DISPLAY_INACTIVE:
	  		  menu_inactive();
	  		  break;
	  	  case DISPLAY_ACTIVE:
	  		  menu_active();
	  		  break;
	  	  default:
	  		  break;
	  }
	  vTaskDelay(pdMS_TO_TICKS(100));
  }
  /* USER CODE END 5 */
}

/* USER CODE BEGIN Header_Imu_Task */
/**
* @brief Function implementing the imu thread.
* @param argument: Not used
* @retval None
*/
/* USER CODE END Header_Imu_Task */
void Imu_Task(void *argument)
{
  /* USER CODE BEGIN Imu_Task */
  /* Infinite loop */
  for(;;)
  {
    osDelay(100);
  }
  /* USER CODE END Imu_Task */
}

/**
  * @brief  This function is executed in case of error occurrence.
  * @retval None
  */
void Error_Handler(void)
{
  /* USER CODE BEGIN Error_Handler_Debug */
  /* User can add his own implementation to report the HAL error return state */
  __disable_irq();
  while (1)
  {
  }
  /* USER CODE END Error_Handler_Debug */
}
#ifdef USE_FULL_ASSERT
/**
  * @brief  Reports the name of the source file and the source line number
  *         where the assert_param error has occurred.
  * @param  file: pointer to the source file name
  * @param  line: assert_param error line source number
  * @retval None
  */
void assert_failed(uint8_t *file, uint32_t line)
{
  /* USER CODE BEGIN 6 */
  /* User can add his own implementation to report the file name and line number,
     ex: printf("Wrong parameters value: file %s on line %d\r\n", file, line) */
  /* USER CODE END 6 */
}
#endif /* USE_FULL_ASSERT */

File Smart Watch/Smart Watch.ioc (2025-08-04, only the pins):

Mcu.UserName=STM32L072CBTx
PA0.Signal=GPXTI0
PA1.Signal=GPIO_Output
PA11.Signal=USB_DM
PA12.Signal=USB_DP
PA15.Signal=GPXTI15
PA2.Signal=GPIO_Output
PA4.Signal=GPIO_Input
PB13.Signal=I2C2_SCL
PB14.Signal=I2C2_SDA
PB6.Signal=I2C1_SCL
PB7.Signal=I2C1_SDA
PC14-OSC32_IN.Signal=RCC_OSC32_IN
PC15-OSC32_OUT.Signal=RCC_OSC32_OUT
PH0-OSC_IN.Signal=RCC_OSC_IN
PH1-OSC_OUT.Signal=RCC_OSC_OUT

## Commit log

2025-07-21 Added PCB to README
2025-07-25 Fixed Black Screen Bug in Menu
    [main.c]
2025-07-26 Added Sensors Page but Needs Work
2025-07-26 Fixed Sensors Page, Working on Temp
    [main.c]
2025-07-27 Commented out the update function by mistake
    [main.c]
2025-07-28 TODO: Swap buttons
2025-07-28 Buttons Swapped
2025-07-28 Double Increment Bug Found - Even after Deboucing
    [main.c]
2025-07-28 Solved Small Bug in Sensors Page
    [main.c]
2025-07-29 Solved a small bug in sensors page
    [main.c]
2025-07-31 Added pedometer to the sensors page
2025-08-04 Simplified button logic & solved a bug
    [main.c]
2025-08-04 Start adding tap detection, currently not working
    [lsm6ds3tr-c.c, main.c]
2025-08-04 Could not find problem with tap detection
    [lsm6ds3tr-c.c]
2025-08-07 Added Schematics, PCB and BOM
    [450404015514.step, BOM.xlsx, DW01A.step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]
2025-08-07 Replaced write register functions
    [lsm6ds3tr-c.c, main.c]
2025-08-07 Added I2C port as a global variable
2025-08-07 Fixed bug in sensors page
    [main.c]
2025-08-08 Fixed a bug and better naming
    [main.c]
2025-08-08 Added register read func & found a bug
    [lsm6ds3tr-c.c]

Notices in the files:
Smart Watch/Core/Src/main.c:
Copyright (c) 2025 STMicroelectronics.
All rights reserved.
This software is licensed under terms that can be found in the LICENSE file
